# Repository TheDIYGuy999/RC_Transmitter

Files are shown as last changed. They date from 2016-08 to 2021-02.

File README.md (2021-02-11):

# This is an Arduino 2.4GHz radio and IR transmitter for Atmel AVR
## Features:
- IR transmitter for "LEGO" Powerfunctions and trains as well as for "MECCANO" motors
- 2.4GHz radio transmitter for RC cars, helicopters etc.
- 4 analog axes, 2 mode switches (joystick buttons)
- 1 potentiometer for adjustments like the MRSC stability control
- 4 push buttons for transmission mode and vehicle selection as well as menu navigation
- 20 seletcable vehicle addresses, so you can use it for more than one vehicle
- 3.3V, 8MHz Pro Mini (a Pro Micro is not supported anymore due to additional functionality)
- STM32 ARM version (deprecated) see: https://github.com/TheDIYGuy999/RC_Transmitter_STM32
- 2.4GHz NRF24L01 radio module
- Support for 0.96" I2C OLED
- Configuration menu for: Channel direction reversing, servo travel adjustment (independent for each vehicle)
- Configuration values are stored in EEPROM
- NRF24L01+PA+LNA SMA radio modules with power amplifier are supported from board version 1.1
- very compact
- Eagle PCB included
- PONG Game included

## Changelog:

New in V 1.3:
- Infrared codes for "MECCANO" IR controlled motors. Separate library required: https://github.com/TheDIYGuy999/MeccanoIr
- Multichannel transmission

New in V 1.4:
- 10 vehicle addresses instead of 5
- The "BACK" button can now be used (if the menu screen is not displayed on the OLED) as a momentary button, for example for a horn on the vehicle. It is sent as "data.momentary1"
- The "A6" potentiometer connector is now integrated in the code and is sent to the vehicle as "data.pot1"
- SimpleTimer library replaced with my own code, which uses significantly less memory
- EEPROM reset function added: press "Select" and "Back" during power on

New in V 1.41:
- Transmitter battery voltage now monitored correctly on 16MHz / 5V systems

New in V 1.42:
- Vehicle battery state change OLED bug fixed

New in V 1.43:
- Radio module sleep mode active while IR mode is in use

New in V 1.5:
- MECCANO IR support enhanced. Requires MECCANO library update to V 1.1

New in V 1.6:
- Buttons locked, if not required in selected transmission mode. This ensures, that no variables can be changed "in background"
- Automatic joystick zero point calibration after transmitter was switched on. This ensures, that you always have precise zero points, even if your potentiometers are not exacltly linear.

New in V 1.7:
- Support for 2 channel car style transmitters with steering wheel
- The transmitter type can be seletced in the new "transmitterConfig.h" file
- The potentiometers in some transmitters hit the mechanical endstop before the end of the electrical range is reached. This can now be compensated with the "range" variable

New in V 1.8:
- In most car style transmitters, the reverse range of the throttle potentiometer is smaller than the forward range.
- The reverse range is now multiplied by 4, to solve this problem

New in V 1.9:
- The "RC_Tester" functionality (https://github.com/TheDIYGuy999/RC_Tester) is now intergrated
- Useful, if you have more than one transmitter. Allows to visualize all 5 analog channels of your transmitter. The radio connection can be easily tested this way.
- Press "Select" during power on. The splash screen shows "Micro RC Tester" instead of "Micro RC Transmitter" and then a graphical screen, which visualizes all analog channels
- Works fo all 10 vehicle addresses

New in V 2.0:
- You have crashed your RC car? Then just play a little PONG session on your transmitter!
- Press "Back" during power on. The transittter is then activating the game mode :-)
- Press the "Back" button again to restart the game after "Game Over" is displayed

New in V 2.01:
- A serious bug in the mapJoystick() function was found during tests with the upcomming STM32 version
- The inverse and scale functionality did not work anymore since V2.0
- The bug is now solved and you can use the adjustments menu again

New in V 2.1:
- 3CH configuration for "car style" transmitter with additional 3 position switch added
- Used for 3 speed gearbox operation, using a single pole, double throw switch, connected to pin A0. Two resistors from A0 to GND and VCC allow 3 servo positions

New in V 2.2:
- 3CH configuration for WLtoys A959 etc. based 3+1CH transmitter (CONFIG_WLTOYS) See pictures below.
- Support for 3 position double throw switches (for gearbox switching etc.) added. Use two identical resistors (ca. 20k) from GND to center pin to VCC across the switch. Define a "CH1Switch" etc. variable., if a switch instead a potentiometer is connected
- New potentiometer calibration variable "reverseEndpoint" allows to adjust the throttle reverse range. Use the "Micro RC Tester" mode on a 2nd transmitter and then adjust the "range" variable as well, until the entire range of all channels is used on the graphical display.
- New "ledInversed" variable allows to use the stock WLtoys LED, which has a red and a green LED in one housing. The common pin is connected to VCC

New in V 2.3:
- 2+2CH configurarion for WLtoys transmitter added (CONFIG_WLTOYS)
- Allows to connect 3 buttons on CH4
- More than 3 buttons would be possible as well, but I ran out of space for more buttons
- Wiring see picture

New in V 2.4:
- Joystick ranges separatly adjustable for each channel in "transmitterConfig.h". This is required for the conversation of some car style transmitters, because they don't use the entire potentiometer range from end stop to end stop.

New in V 2.5:
- 20 vehicle addresses instead of 10
- Less RAM usage

New in V 2.51:
- Libraries comments added

## Usage

See pictures
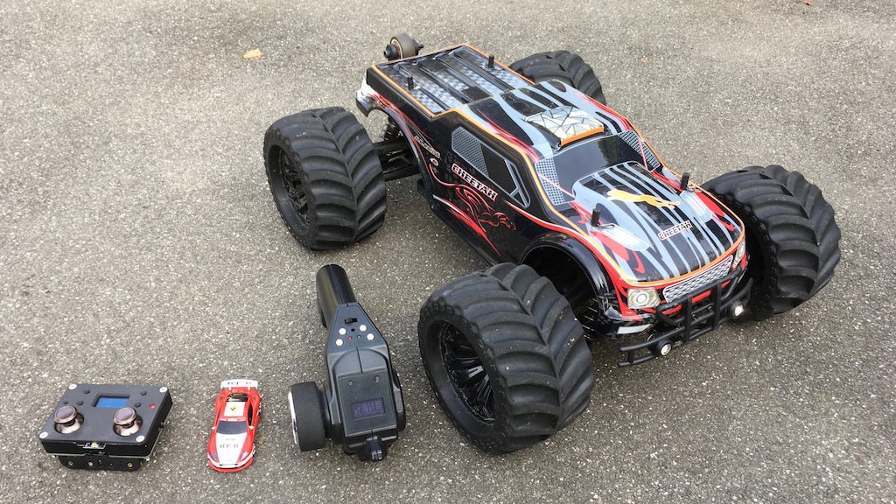
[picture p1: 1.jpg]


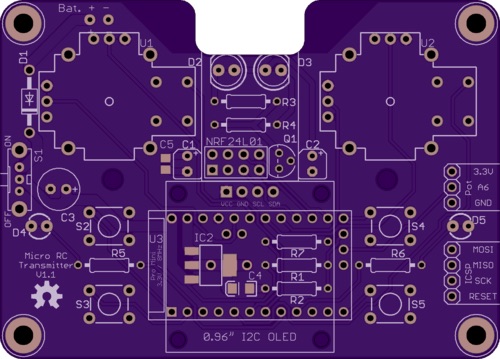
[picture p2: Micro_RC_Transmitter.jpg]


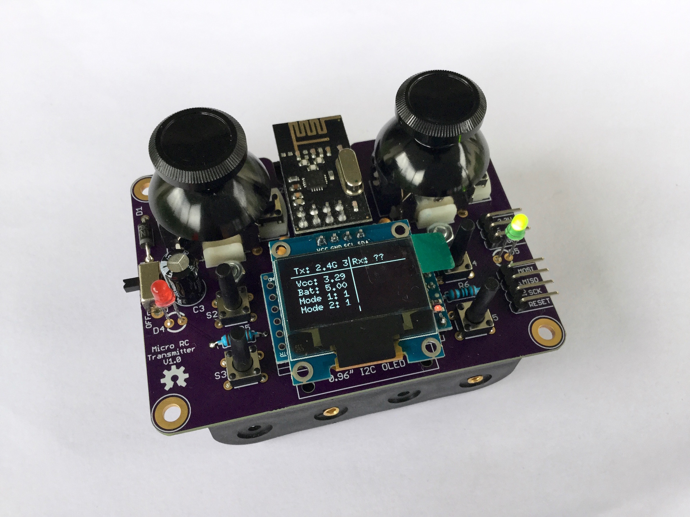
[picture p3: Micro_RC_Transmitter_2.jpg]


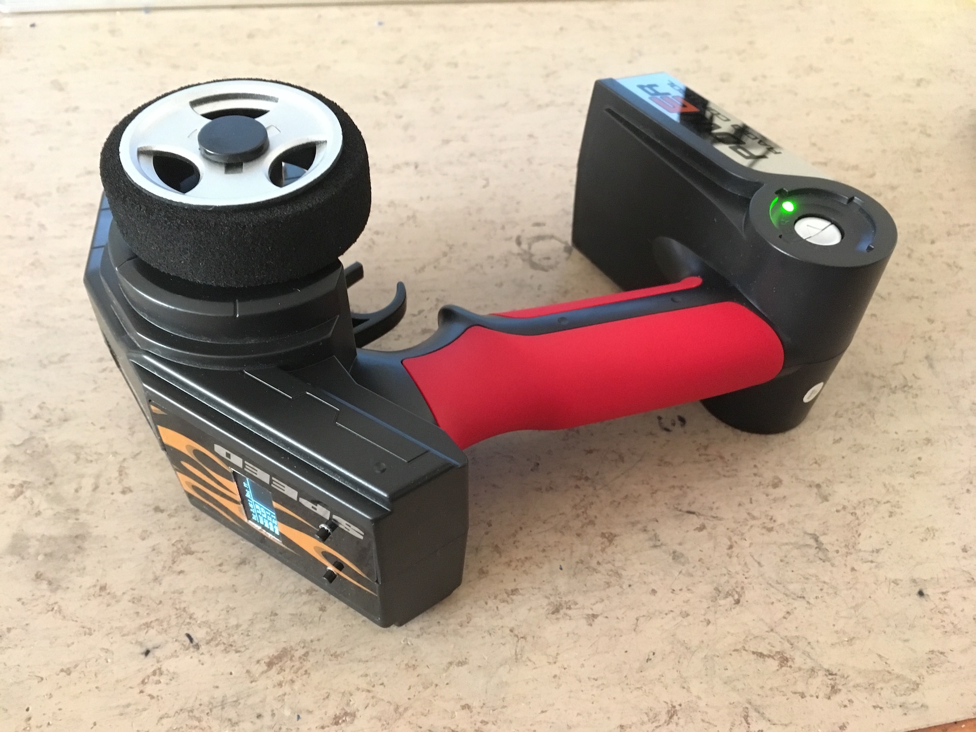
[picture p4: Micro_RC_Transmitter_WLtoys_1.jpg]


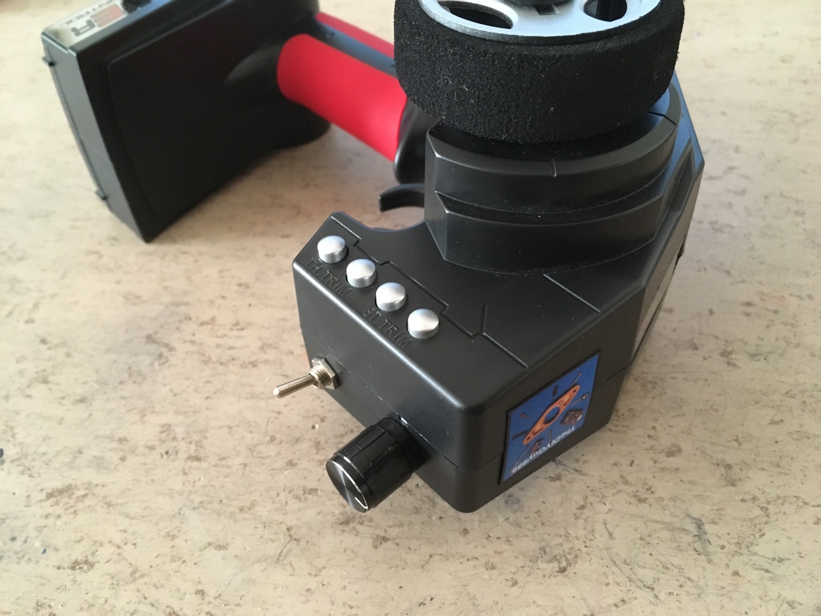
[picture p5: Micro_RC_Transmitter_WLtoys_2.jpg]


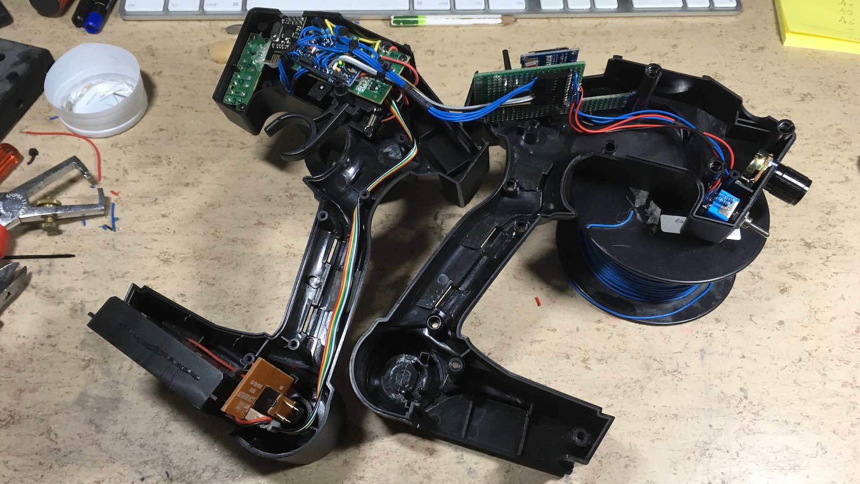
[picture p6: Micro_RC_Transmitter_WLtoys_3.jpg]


3 buttons wired to CH4
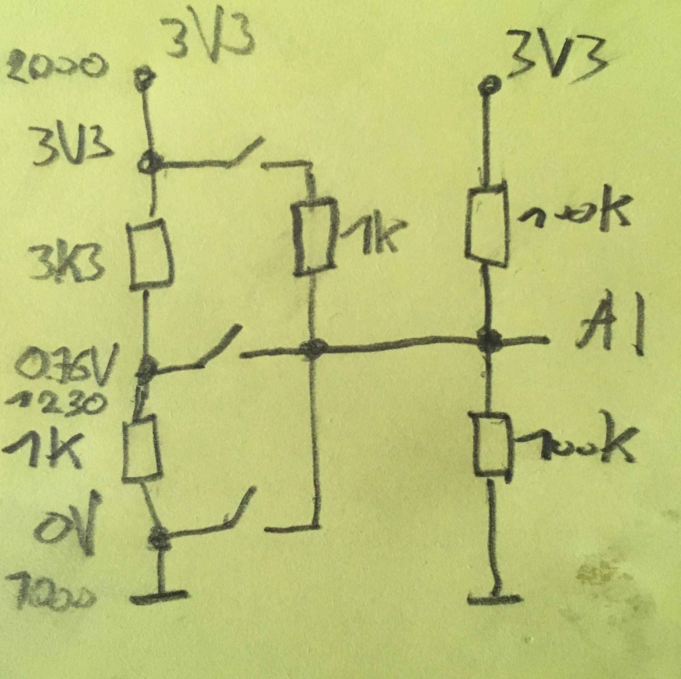
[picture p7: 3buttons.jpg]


3 position rocker switch wired to CH2 (for 3 speed transmission)
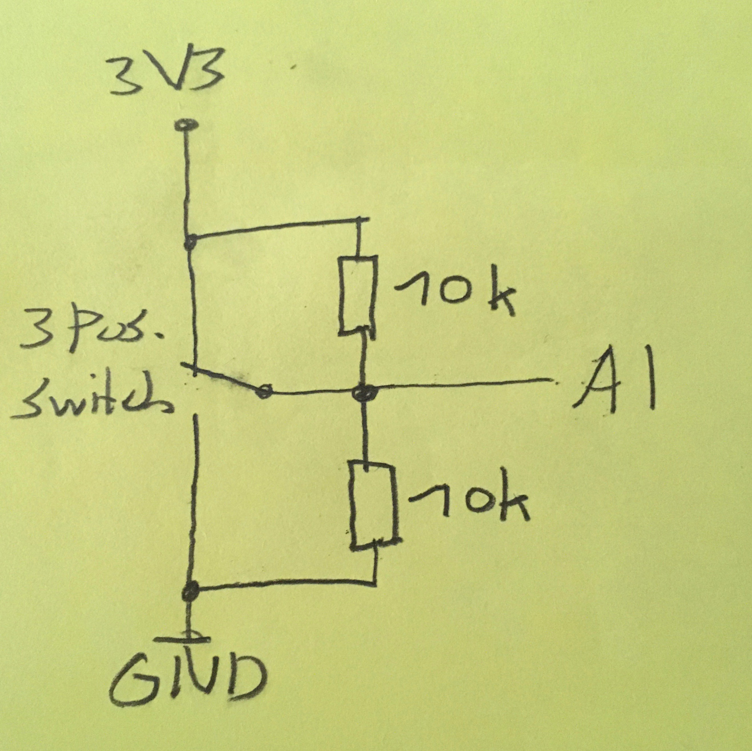
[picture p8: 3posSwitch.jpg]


(c) 2016-2020 TheDIYGuy999

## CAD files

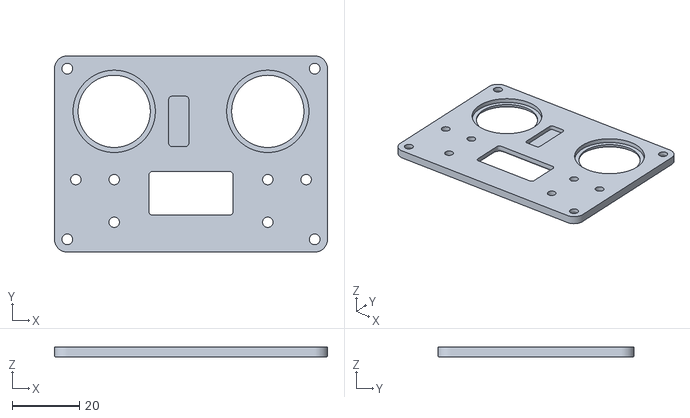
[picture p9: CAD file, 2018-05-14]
Housing/Transmitter Cover.stl
81.3 x 58.4 x 3.00

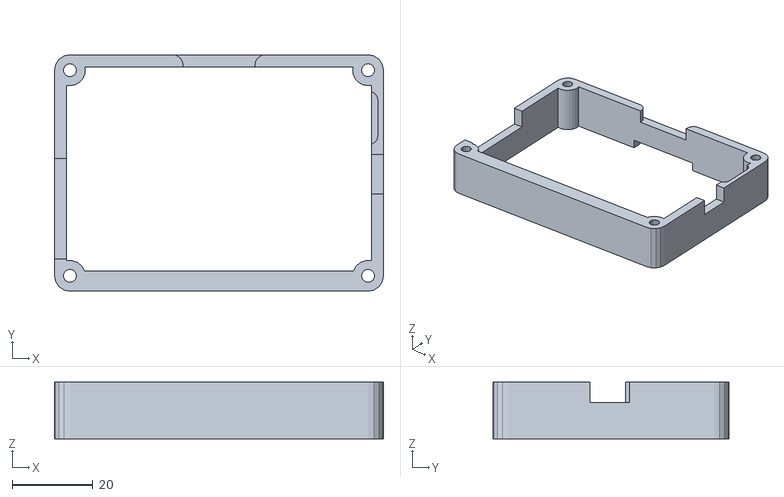
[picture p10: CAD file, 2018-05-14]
Housing/Transmitter Frame.stl
81.3 x 58.4 x 14.0

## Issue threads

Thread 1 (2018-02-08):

BOM missing

ybunyak, 2018-02-08:
Hi,

Is it possible to provide BOM for the transmitter, like you did for Micro_RC_Receiver?

Thanks.

johnlenfr, 2020-04-11:
In the Eagle File you can find the BOM

glisandro, 2023-05-11:
joysticks are those of XBOX?

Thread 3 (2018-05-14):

Housing

ybunyak, 2018-05-14:
Could you please share .stl files for the housing like you did for the receiver?

TheDIYGuy999, 2018-05-14:
Sorry for the delay. They are now available.

ybunyak, 2018-05-14:
Thank you. Will post images of my project when it's done ;)

Closed 2018-05-14.

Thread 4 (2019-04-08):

Question: RC Transmitter

JpEncausse, 2019-04-08:
Hi,
Sorry if my question is stupid,

I'd like to setup an "Arduino Bridge" between an RC Car WLtoys K989 and a computer.
Sending WebSocket/HTTP command to the Arduino then to the RC Car Receiver.
(Yes I know, lag will be a problem)

Should I start with RC_Transmitter repository code ? Or is there a lighweight version / article ?
Thanks

jindaxia, 2019-05-19:
ESP8266 ?

TheDIYGuy999, 2019-05-19:
There is no ESP8266 version, but one for STM32: https://github.com/TheDIYGuy999/RC_Transmitter_STM32

Ahmedabdulamir, 2019-05-28:
Hi, I want to start building similar transmitter. Do I need Pro Mini 168 or 328 for the transmitter?. Also what about the receiver?

I like your work BTW, its so proffessional

Thanks

TheDIYGuy999, 2019-05-28:
Hi,  you need the 328 version. Both the transmitter and the receiver use the same Atmel IC.

Also have a look at the manual in the transmitter section.

Thanks for the praise

Ahmedabdulamir, 2019-05-28:
Thanks for you kind reply. Can I use 5v Pro mini instead of 3.3v version?

jindaxia, 2019-05-29:
#5   YES！

TheDIYGuy999, 2019-05-29:
Yes, but you have to make sure, that your battery voltage is at least 5.5V (before the 5V regulator) and that your radio module is supplied with 3.3V, using a separate regulator.

jindaxia, 2019-05-30:
now I use 16M/3.3v， it‘s ok
I replaced the MIC5205 with a 3.3v version on the board， the MIC5205-3.3 is very easy to get，

Ahmedabdulamir, 2019-05-30:
Thanks I got it. I think its best to use the 3.3v instead of using another regulator for the RF module. Thanks to all for your comments

sosssego, 2021-01-28:
Can I use this to make 3 rc car/radios to work together?

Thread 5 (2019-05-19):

What will happening if I use the 5V/16Mhz pro mini

jindaxia, 2019-05-19:
I only have 5v/16mhz pro mini ， how if i can use this board？

TheDIYGuy999, 2019-05-19:
You can use it, but make sure the NRF24 radio module is supplied by 3.3V. Also make sure, that your minimum battery voltage is about 5.7V

jindaxia, 2019-05-20:
Thanks，

jindaxia, 2019-05-21:
finally，  I replaced the MIC2505 with the 3.3v version on the board

Closed 2019-05-20.

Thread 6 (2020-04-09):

Connection/pairing problem

Kiriki-kun, 2020-04-09:
Hi,

I assembled transmitter and receiver.
Transmitter is working, i can operate menu.
I can't verify if receiver is working, because there is no indication of work.
Receiver should be set to ID 1.
I checked the radio voltage and all connections. They are good.

When i power up the receiver and transmitter, they won't connect.
Is there another step to pair them?
Do you have any suggestion what to check?
After few hours I'm out of ideas.

Thanks for help
Kiriki

TheDIYGuy999, 2020-04-09:
Hi, really hard to tell. The code is uploading without issues? If you have a 2nd transmitter, you can also use it as a receiver with graphical feedback, according to the manual.

Are you sure your receiver is programmed with ID 1? Maybe, one of your NRF24 radio modules is defective?

Kiriki-kun, 2020-04-09:
Thank you for your answer.
I have problem with verificatio after writing, but writing is working good. I flashed different configuration to transmitter, and i could see the difference after turning it on.
I dont have second transmitter, i will order parts if everything else fail (i used all my spare sparts just to make one run :)).
I will try to write simple code just to test if radio modules are working.

So i assume, that transmitter and receiver should pair after couple of seconds, without additional steps? Just turn both on, and wait?

Kiriki-kun, 2020-04-10:
Can it be because i have 16 Mhz arduino in transmitter, and 8 Mhz in receiver?

TheDIYGuy999, 2020-04-10:
No, it does not matter (if your boot loader is the right one for the frequency), but what is your transmitter battery voltage? Is it high enough for stable 5V VCC? And yes, they should pair immediately, if they are on the same channel. You could try to add a 100nF ceramic capacitor across the NFRF module 3.3V & GND pins, it makes the receiver radio much more stable, at least in my case. All the solder joints are looking god with a magnifier? Maybe you can post pictures?

johnlenfr, 2020-04-11:
@Kiriki-kun : seams like you have a problem with initialization of NRF24.

Test your NRF24 with simple code before testing the transmiter code of @TheDIYGuy999

See https://forum.arduino.cc/index.php?topic=421081.0

Kiriki-kun, 2020-04-17:
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
Hi,
Right now, i managed to setup serial monitor and run debug code. I'm attaching printed debug.
I can see that all anthena parameters are empty, but i'm not sure if they are not filled after establishing the connection.
Can you look at it? This is how debug should look like for not connected transmitter or receiver?

Kiriki-kun, 2020-04-22:
ok, i made it work.
Not really sure what wasn't working. I tried few test programs, resoldered radios, and now it's working :)
Thank you very much for yor help :)

TheDIYGuy999, 2020-04-22:
Great. I knew you would solve the issue. Well done and have fun with it. I would love to see pictures of your work, if possible. And sorry, I forgot to answer your previous question.

Closed 2020-04-22.

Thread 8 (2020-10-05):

Expected variable ranges

debonthj, 2020-10-05:
Great project! I am building this into a RC car style pistol grip transmitter, different brand though than the WLToys. What are the expected ranges of the wheel left/right and throttle fwd/rev that are being sent to the receiver? What I am getting right now:

Throttle: fwd = 72, mid = 50, rev = 37
Steer: left = 37, mid = 50, right =63.

Is this correct or should it be a range between 0-100?

I may not be understanding this correctly:

`// Joystick calibration
int range = 1023; // 1023, if entire pot wiper range is used
int reverseEndpoint = 0; // the point, where the throttle joystick hits its reverse end stop
`

debonthj, 2020-10-05:
These are the raw values from the signal wires of the throttle and steering wheel pots via AnalogRead on A1 (steering) and A3 (throttle), pots powered by 5V and GND.

A1 (steering)

- 320 (left)
- 447 (neutral)
- 585 (right)

A3 (throttle)

- 682 (go)
- 460 (neutral)
- 332 (rev)

debonthj, 2020-10-05:
Thanks. Through trial and error I got a good range setting (640). This gives me the full range for steering, as well as the throttle reverse, but for throttle FWD it gets to 100 at around 2/3 of the trigger position. reverseEndpoint does not seem to have an impact. I suppose a separate range is needed for steering and throttle given the differences in their resistances as per above. Not a huge issue but something I may code in in the future if this project gets alot of use. FYI the transmitter is this: https://www.carson-modelsport.com/en/products/carson-modelsport/accessories/radio-controls/reflex-wheel-start-24g-radio-white-500500103/

Thanks again!

TheDIYGuy999, 2020-10-05:
Thanks for the feedback. Yes, a separate range might be useful, but for my transmitters it was not required so far.

Closed 2020-10-05.

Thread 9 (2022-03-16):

| Question | Is there a wiring diagram or documentation for the "2+1 channel car type" transmitter?

zinixyt, 2022-03-16:
Hi, is there any documentation or diagrams for the transmitter type above that im missing?
If yes then i need help.

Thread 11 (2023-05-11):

Problem with screen pins

glisandro, 2023-05-11:
Hi,
The OLED screen I have has the GND and VCC pins swapped with respect to the pcb

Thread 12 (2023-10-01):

Can not seem to get it to verify

hendr13x, 2023-10-01:
HI I'm using Arduino IDE 2.2.1

opening a fresh copy of the RC Transmitter code and I believe all the required Library's including your version on statusLED
i can not seem to get the code to verify
 it gets to greenLED.begin(6); // Green LED on pin 5
and gets the following error
Compilation error: no matching function for call to 'statusLED::begin(int)'

im at a loss as to what i have done wrong with it.

any help would be appreciated or if you are able to send or upload a complete with all included files.

Thank you

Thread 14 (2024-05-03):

Compilation error for the Arduino Pro or Pro Mini board

01makar, 2024-05-03:
hello. I'm trying to flash the transmitter, but when compiling the sketch it gives an error: "Compilation error for the Arduino Pro or Pro Mini board." please tell me how to fix it.

01makar, 2024-05-06:
I recorded the bootloader, when recording the transmitter sketch through the programmer after compilation, it displays the following message: Compilation error for TheDIYGuy999 328P board (8 MHz ext. Oscillator)

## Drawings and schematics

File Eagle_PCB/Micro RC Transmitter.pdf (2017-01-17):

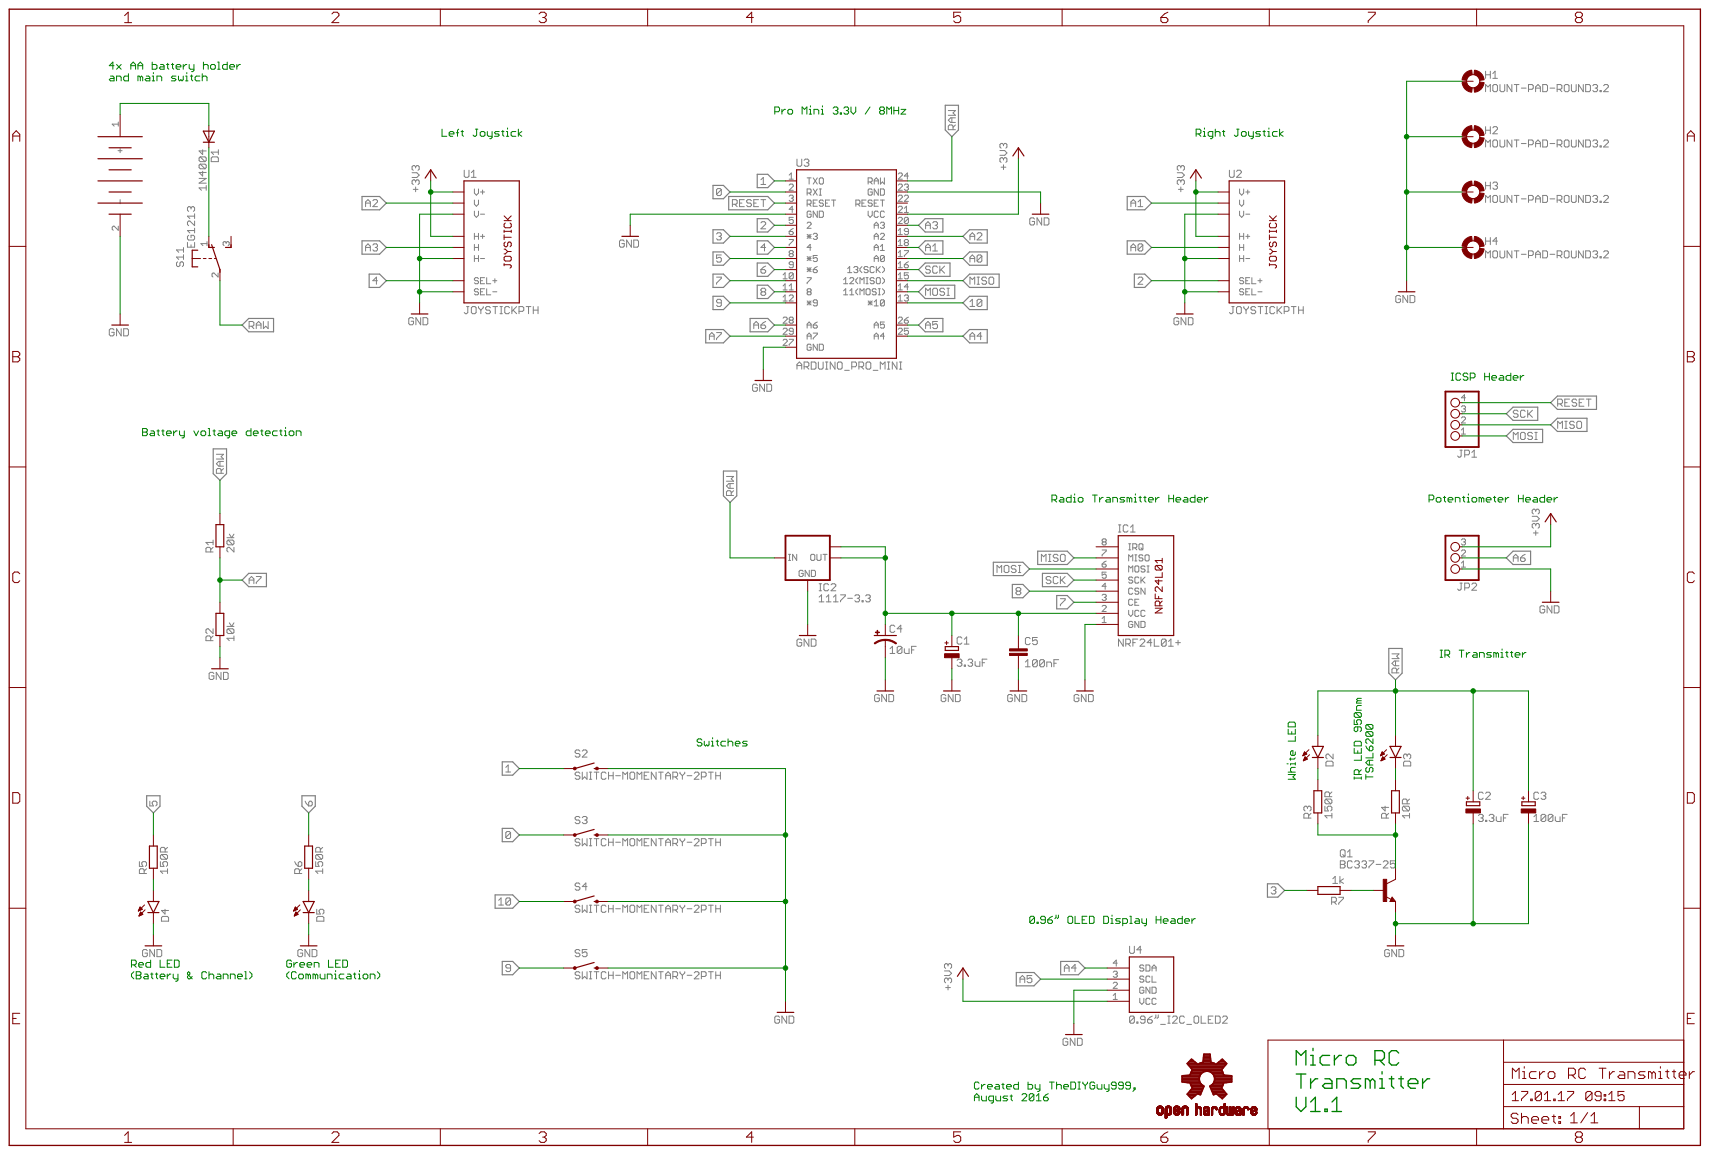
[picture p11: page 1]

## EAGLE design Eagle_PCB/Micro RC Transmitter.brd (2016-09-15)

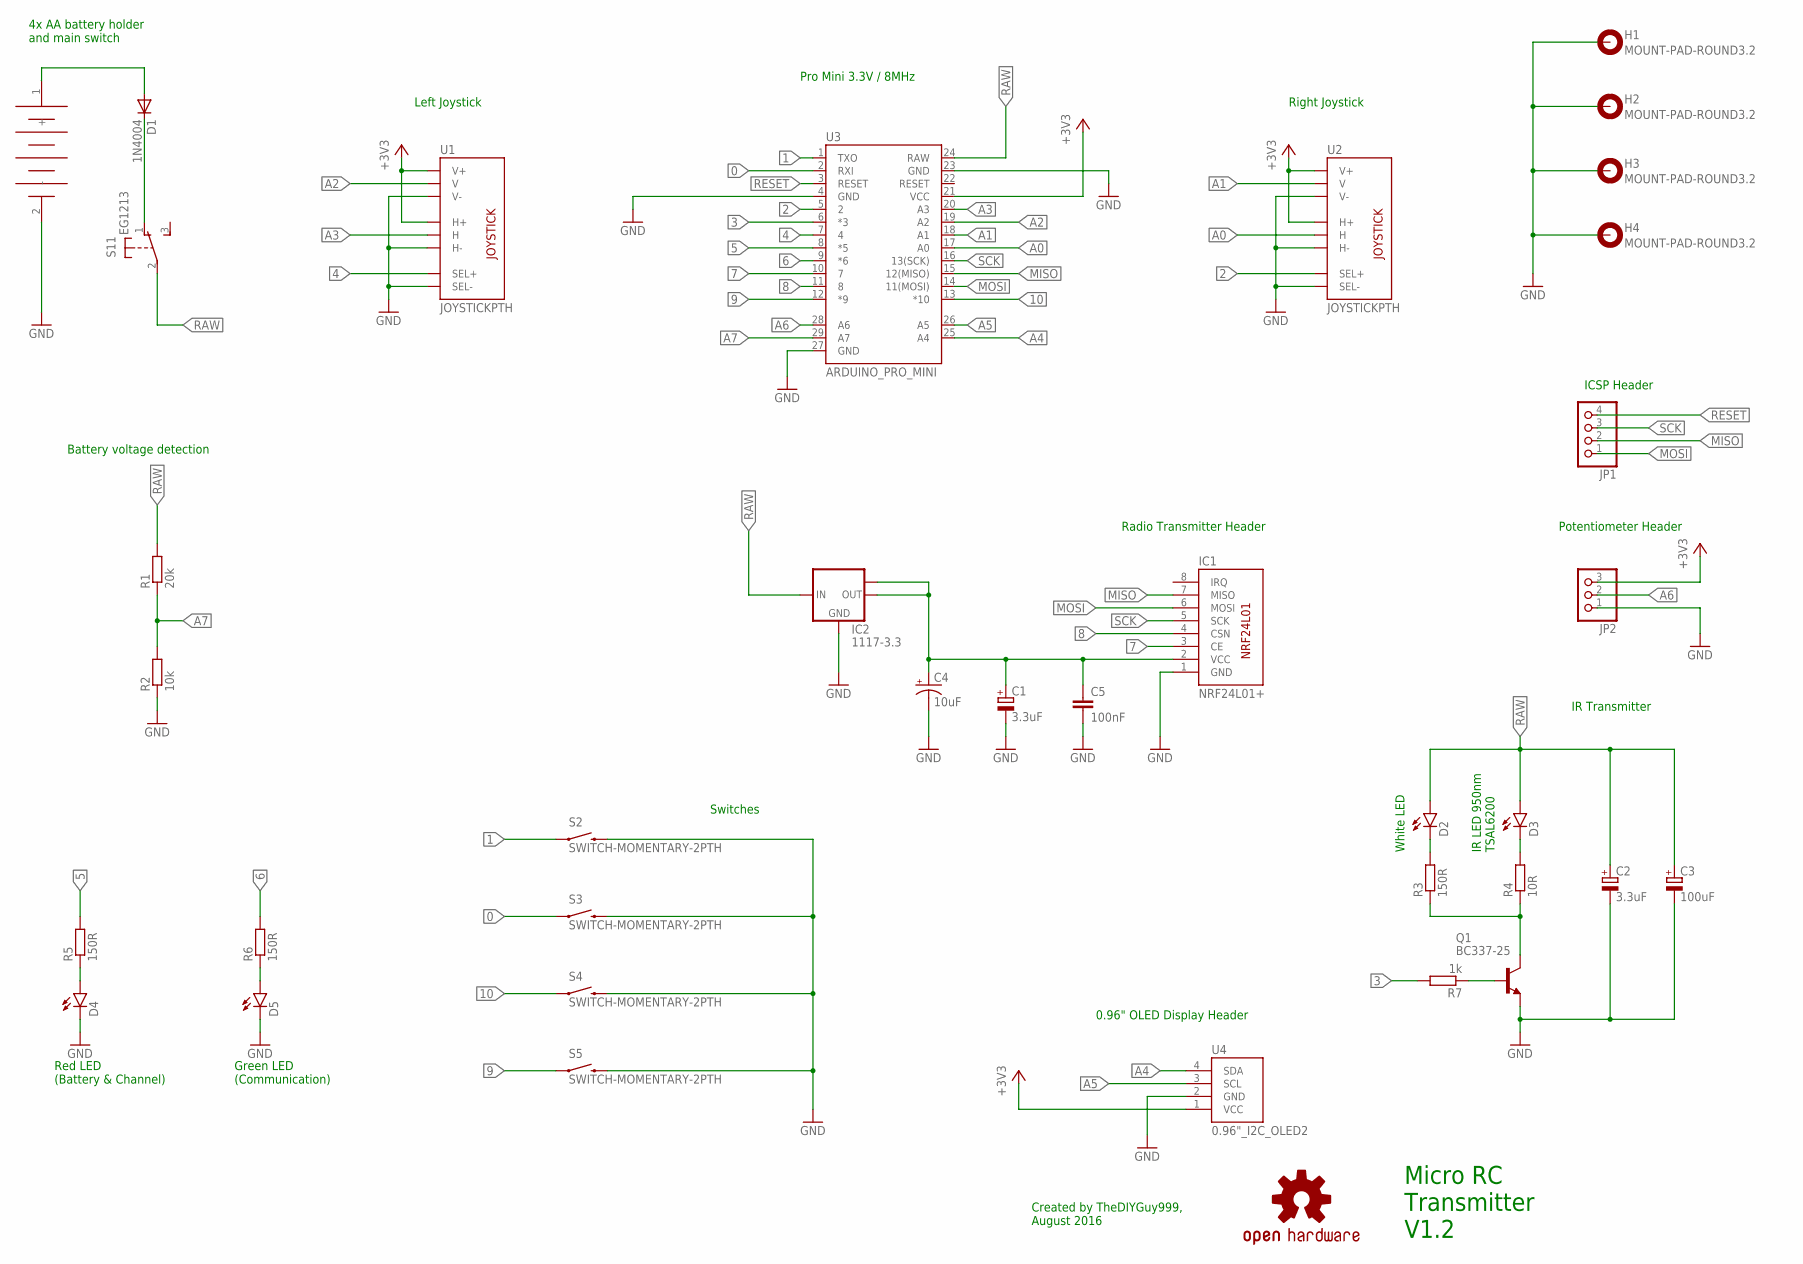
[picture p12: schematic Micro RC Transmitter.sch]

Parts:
C1, C2: 3.3uF; B45181A
C3: 100uF; E2,5-7
C4: 10uF; EIA3216
C5: 100nF; C0805
D1: 1N4004; DO41-10
D2, D3: LED5MM
D4, D5: LED3MM
G1: 4X_AA_BATTERY_HOLDER
H1, H2, H3, H4: MOUNT-PAD-ROUND3.2; 3,2-PAD
IC1: NRF24L01+; NRF24L01
IC2: 1117-3.3; SOT223
JP1: PINHD-1X4; 1X04
JP2: PINHD-1X3; 1X03
LOGO1: OSHW-LOGOM; OSHW-LOGO-M
Q1: BC337-25; TO92
R1: 20k; 0207/10
R2: 10k; 0207/10
R3, R5, R6: 150R; 0207/10
R4: 10R; 0207/10
R7: 1k; 0207/10
S1: EG1213
S2, S3, S4, S5: SWITCH-MOMENTARY-2PTH; TACTILE-PTH
U1, U2: JOYSTICKPTH; JOYSTICK
U3: ARDUINO_PRO_MINI
U4: 0.96"_I2C_OLED2; 0.96"_I2C_OLED_2

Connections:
0: S3.1, U3.2 (RXI)
1: S2.1, U3.1 (TXO)
2: U2.B1A (SEL+), U3.5 (2)
3: R7.2, U3.6 (*3)
4: U1.B1A (SEL+), U3.7 (4)
5: R5.2, U3.8 (*5)
6: R6.2, U3.9 (*6)
7: IC1.3 (CE), U3.10 (7)
8: IC1.4 (CSN), U3.11 (8)
9: S5.1, U3.12 (*9)
10: S4.1, U3.13 (*10)
+3V3: JP2.3, U1.H1 (H+), U1.V1 (V+), U2.H1 (H+), U2.V1 (V+), U3.21 (VCC), U4.1 (VCC)
A0: U2.H2 (H), U3.17 (A0)
A1: U2.V2 (V), U3.18 (A1)
A2: U1.V2 (V), U3.19 (A2)
A3: U1.H2 (H), U3.20 (A3)
A4: U3.25 (A4), U4.4 (SDA)
A5: U3.26 (A5), U4.3 (SCL)
A6: JP2.2, U3.28 (A6)
A7: R1.1, R2.2, U3.29 (A7)
GND: C1.-, C2.-, C3.-, C4.C (-), C5.2, D4.K (C), D5.K (C), G1.2 (-), H1.B3,2, H2.B3,2, H3.B3,2, H4.B3,2, IC1.1 (GND), IC2.1 (GND), JP2.1, Q1.1 (E), R2.1, S2.3 (2), S3.3 (2), S4.3 (2), S5.3 (2), U1.B2A (SEL-), U1.H3 (H-), U1.V3 (V-), U2.B2A (SEL-), U2.H3 (H-), U2.V3 (V-), U3.4 (GND), U3.23 (GND), U3.27 (GND), U4.2 (GND)
MISO: IC1.7 (MISO), JP1.2, U3.15 (12(MISO))
MOSI: IC1.6 (MOSI), JP1.1, U3.14 (11(MOSI))
unnamed: D4.A, R5.1
unnamed: D5.A, R6.1
unnamed: Q1.3 (C), R3.1, R4.1
unnamed: D3.K (C), R4.2
unnamed: Q1.2 (B), R7.1
unnamed: D2.K (C), R3.2
unnamed: D1.A, G1.1 (+)
unnamed: D1.C, S1.1 (O)
unnamed: C1.+, C4.A (+), C5.1, IC1.2 (VCC), IC2.2 (OUT), IC2.TAB (OUT1)
RAW: C2.+, C3.+, D2.A, D3.A, IC2.3 (IN), R1.2, S1.2, U3.24 (RAW)
RESET: JP1.4, U3.3 (RESET)
SCK: IC1.5 (SCK), JP1.3, U3.16 (13(SCK))

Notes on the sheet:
Red LED (Battery & Channel)
Green LED (Communication)
Micro RC Transmitter V1.2
White LED
IR LED 950nm TSAL6200
IR Transmitter
Radio Transmitter Header
4x AA battery holder and main switch
Left Joystick
Right Joystick
0.96" OLED Display Header
Battery voltage detection
Switches
ICSP Header
Pro Mini 3.3V / 8MHz
Potentiometer Header
Created by TheDIYGuy999, August 2016

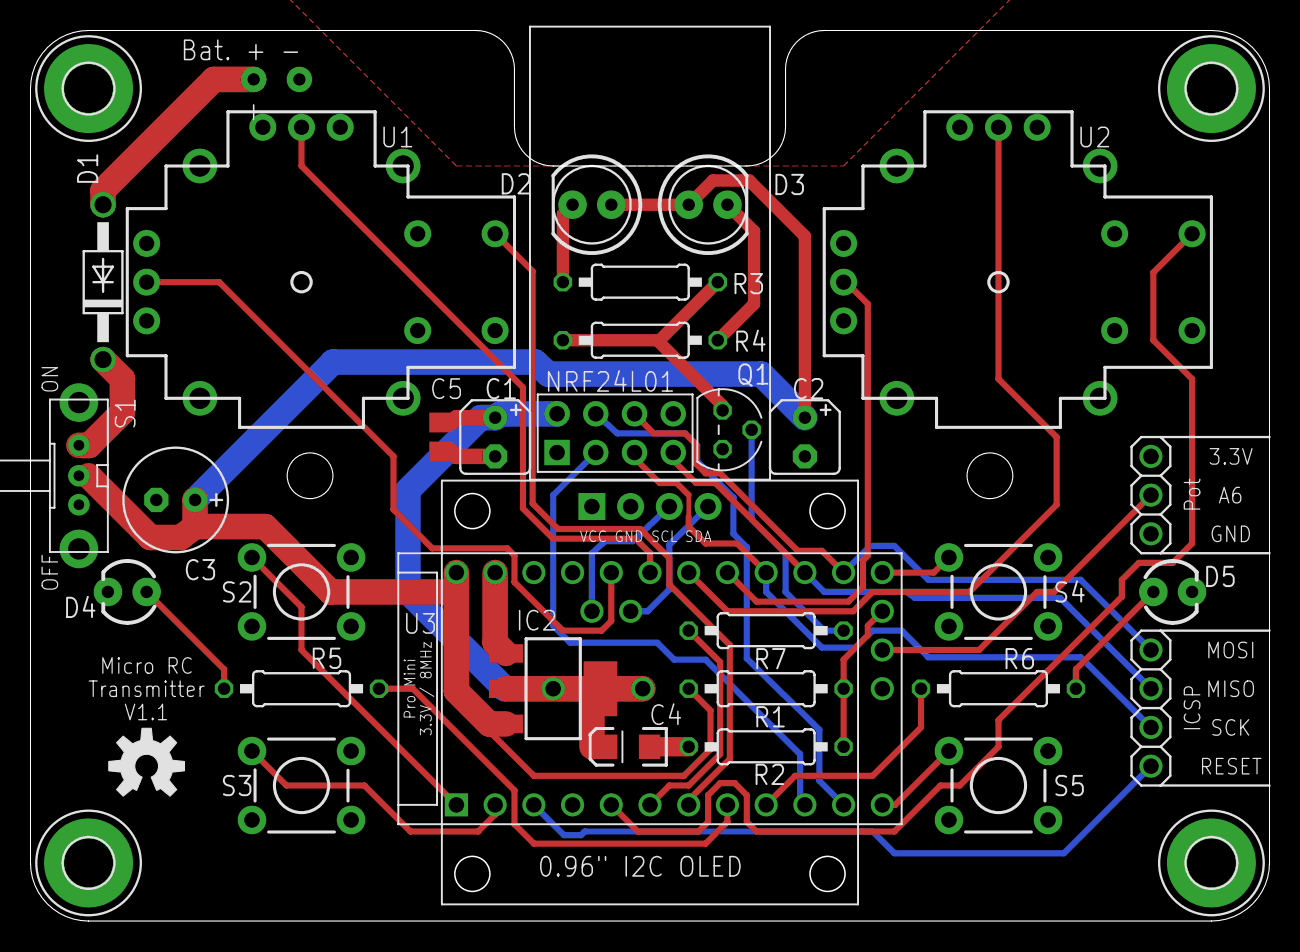
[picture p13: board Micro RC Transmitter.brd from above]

Board: 2 copper layers, 81.3 x 58.4 mm, 37 parts (1 on the bottom side), 35 nets.

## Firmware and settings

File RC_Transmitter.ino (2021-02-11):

// Micro RC Project. A tiny little 2.4GHz and LEGO "Power Functions" / "MECCANO" IR RC transmitter!
// 3.3V, 8MHz Pro Mini
// STM32F103C8T6 ARM version see: https://github.com/TheDIYGuy999/RC_Transmitter_STM32
// 2.4GHz NRF24L01 radio module
// SSD 1306 128 x 63 0.96" OLED
// Custom PCB from OSH Park
// Menu for the following adjustments:
// -Channel reversing
// -Channel travel limitation adjustable in steps of 5%
// -Value changes are stored in EEPROM, individually per vehicle
// Radio transmitter tester included (press "Select" button during power up)
// NRF24L01+PA+LNA SMA radio modules with power amplifier are supported from board version 1.1
// ATARI PONG game :-) Press the "Back" button during power on to start it

const float codeVersion = 2.51; // Software revision

//
// =======================================================================================================
// BUILD OPTIONS (comment out unneeded options)
// =======================================================================================================
//

//#define DEBUG // if not commented out, Serial.print() is active! For debugging only!!
//#define OLED_DEBUG // if not commented out, an additional diagnostics screen is shown during startup

//
// =======================================================================================================
// INCLUDE LIRBARIES & TABS
// =======================================================================================================
//

// Libraries
#include <SPI.h>
#include <RF24.h> // Installed via Sketch > Include Library > Manage Libraries > Type "RF24" (use V1.3.3!)
#include <printf.h>
#include <EEPROMex.h> // https://github.com/thijse/Arduino-EEPROMEx
#include <LegoIr.h> // https://github.com/TheDIYGuy999/LegoIr
#include <statusLED.h> // https://github.com/TheDIYGuy999/statusLED
#include <U8glib.h> // Installed via Sketch > Include Library > Manage Libraries > Type "U8glib"

// Tabs
#include "transmitterConfig.h"
// More tabs (.h files in the sketch directory) see further down

//
// =======================================================================================================
// PIN ASSIGNMENTS & GLOBAL VARIABLES
// =======================================================================================================
//

// Is the radio or IR transmission mode active?
byte transmissionMode = 1; // Radio mode is active by default

// Select trannsmitter operation mode
byte operationMode = 0; // Start in transmitter mode (0 = transmitter mode, 1 = tester mode, 2 = game mode)

// Vehicle address
int vehicleNumber = 1; // Vehicle number one is active by default

// Radio channels (126 channels are supported)
byte chPointer = 0; // Channel 1 (the first entry of the array) is active by default
const byte NRFchannel[] {
  1, 2
};

// the ID number of the used "radio pipe" must match with the selected ID on the transmitter!
// 20 ID's are available @ the moment
const uint64_t pipeOut[] PROGMEM = {
  0xE9E8F0F0B1LL, 0xE9E8F0F0B2LL, 0xE9E8F0F0B3LL, 0xE9E8F0F0B4LL, 0xE9E8F0F0B5LL,
  0xE9E8F0F0B6LL, 0xE9E8F0F0B7LL, 0xE9E8F0F0B8LL, 0xE9E8F0F0B9LL, 0xE9E8F0F0B0LL,
  0xE9E8F0F0C1LL, 0xE9E8F0F0C2LL, 0xE9E8F0F0C3LL, 0xE9E8F0F0C4LL, 0xE9E8F0F0C5LL,
  0xE9E8F0F0C6LL, 0xE9E8F0F0C7LL, 0xE9E8F0F0C8LL, 0xE9E8F0F0C9LL, 0xE9E8F0F0C0LL
};
const int maxVehicleNumber = (sizeof(pipeOut) / (sizeof(uint64_t)));

// Hardware configuration: Set up nRF24L01 radio on hardware SPI bus & pins 7 (CE) & 8 (CSN)
RF24 radio(7, 8);

// The size of this struct should not exceed 32 bytes
struct RcData {
  byte axis1; // Aileron (Steering for car)
  byte axis2; // Elevator
  byte axis3; // Throttle
  byte axis4; // Rudder
  boolean mode1 = false; // Mode1 (toggle speed limitation)
  boolean mode2 = false; // Mode2 (toggle acc. / dec. limitation)
  boolean momentary1 = false; // Momentary push button
  byte pot1; // Potentiometer
};
RcData data;

// This struct defines data, which are embedded inside the ACK payload
struct ackPayload {
  float vcc; // vehicle vcc voltage
  float batteryVoltage; // vehicle battery voltage
  boolean batteryOk; // the vehicle battery voltage is OK!
  byte channel = 1; // the channel number
};
ackPayload payload;

// Did the receiver acknowledge the sent data?
boolean transmissionState;

// LEGO powerfunctions IR
LegoIr pf;
int pfChannel;
const int pfMaxAddress = 3;

// TX voltages
boolean batteryOkTx = false;
#define BATTERY_DETECT_PIN A7 // The 20k & 10k battery detection voltage divider is connected to pin A7
float txVcc;
float txBatt;

//Joystick reversing
boolean joystickReversed[maxVehicleNumber + 1][4] = { // 1 + 10 Vehicle Addresses, 4 Servos
  {false, false, false, false}, // Address 0 used for EEPROM initialisation

  {false, false, false, false}, // Address 1
  {false, false, false, false}, // Address 2
  {false, false, false, false}, // Address 3
  {false, false, false, false}, // Address 4
  {false, false, false, false}, // Address 5
  {false, false, false, false}, // Address 6
  {false, false, false, false}, // Address 7
  {false, false, false, false}, // Address 8
  {false, false, false, false}, // Address 9
  {false, false, false, false}, // Address 10
};

//Joystick percent negative
byte joystickPercentNegative[maxVehicleNumber + 1][4] = { // 1 + 10 Vehicle Addresses, 4 Servos
  {100, 100, 100, 100}, // Address 0 not used

  {100, 100, 100, 100}, // Address 1
  {100, 100, 100, 100}, // Address 2
  {100, 100, 100, 100}, // Address 3
  {100, 100, 100, 100}, // Address 4
  {100, 100, 100, 100}, // Address 5
  {100, 100, 100, 100}, // Address 6
  {100, 100, 100, 100}, // Address 7
  {100, 100, 100, 100}, // Address 8
  {100, 100, 100, 100}, // Address 9
  {100, 100, 100, 100}, // Address 10
};

//Joystick percent positive
byte joystickPercentPositive[maxVehicleNumber + 1][4] = { // 1 + 10 Vehicle Addresses, 4 Channels
  {100, 100, 100, 100}, // Address 0 not used

  {100, 100, 100, 100}, // Address 1
  {100, 100, 100, 100}, // Address 2
  {100, 100, 100, 100}, // Address 3
  {100, 100, 100, 100}, // Address 4
  {100, 100, 100, 100}, // Address 5
  {100, 100, 100, 100}, // Address 6
  {100, 100, 100, 100}, // Address 7
  {100, 100, 100, 100}, // Address 8
  {100, 100, 100, 100}, // Address 9
  {100, 100, 100, 100}, // Address 10
};

// Joysticks
#define JOYSTICK_1 A1
#define JOYSTICK_2 A0
#define JOYSTICK_3 A3
#define JOYSTICK_4 A2

// Joystick push buttons
#define JOYSTICK_BUTTON_LEFT 4
#define JOYSTICK_BUTTON_RIGHT 2

byte leftJoystickButtonState;
byte rightJoystickButtonState;

// Buttons
#define BUTTON_LEFT 1 // - or channel select
#define BUTTON_RIGHT 10 // + or transmission mode select
#define BUTTON_SEL 0 // select button for menu
#define BUTTON_BACK 9 // back button for menu

byte leftButtonState = 7; // init states with 7 (see macro below)!
byte rightButtonState = 7;
byte selButtonState = 7;
byte backButtonState = 7;

// macro for detection of rising edge and debouncing
/*the state argument (which must be a variable) records the current and the last 3 reads
  by shifting one bit to the left at each read and bitwise anding with 15 (=0b1111).
  If the value is 7(=0b0111) we have one raising edge followed by 3 consecutive 1's.
  That would qualify as a debounced raising edge*/
#define DRE(signal, state) (state=(state<<1)|(signal&1)&15)==7

// Status LED objects (false = logic not inverted)
#ifdef ledInversed // inversed logic
statusLED greenLED(true); // green: ON = transmitter ON, flashing = Communication with vehicle OK
statusLED redLED(true); // red: ON = battery empty
#endif
#ifndef ledInversed // not inversed logic
statusLED greenLED(false); // green: ON = transmitter ON, flashing = Communication with vehicle OK
statusLED redLED(false); // red: ON = battery empty
#endif

// OLED display. Select the one you have! Otherwise sthe sreen could be slightly offset sideways!
//U8GLIB_SH1106_128X64 u8g(U8G_I2C_OPT_FAST);  // I2C / TWI  FAST instead of NONE = 400kHz I2C!
U8GLIB_SSD1306_128X64 u8g(U8G_I2C_OPT_FAST);  // I2C / TWI  FAST instead of NONE = 400kHz I2C!
int activeScreen = 0; // the currently displayed screen number (0 = splash screen)
boolean displayLocked = true;
byte menuRow = 0; // Menu active cursor line

// EEPROM (max. total size is 512 bytes)
// Always get the adresses first and in the same order
// Blocks of 21 x 4 bytes = 84 bytes each!
int addressReverse = EEPROM.getAddress(sizeof(byte) * 84);
int addressNegative = EEPROM.getAddress(sizeof(byte) * 84);
int addressPositive = EEPROM.getAddress(sizeof(byte) * 84);

//
// =======================================================================================================
// INCLUDE TABS (header files in sketch directory)
// =======================================================================================================
//

// Tabs (header files in sketch directory)
#include "readVCC.h"
//#include "transmitterConfig.h"
#include "MeccanoIr.h" // https://github.com/TheDIYGuy999/MeccanoIr
#include "pong.h" // A little pong game :-)
#include "pgmRead64.h" // Read 64 bit blocks from PROGMEM

//
// =======================================================================================================
// RADIO SETUP
// =======================================================================================================
//

void setupRadio() {
  radio.begin();
  radio.setChannel(NRFchannel[chPointer]);

  radio.powerUp();

  // Set Power Amplifier (PA) level to one of four levels: RF24_PA_MIN, RF24_PA_LOW, RF24_PA_HIGH and RF24_PA_MAX
  if (boardVersion < 1.1 ) radio.setPALevel(RF24_PA_MIN); // No independent NRF24L01 3.3V PSU, so only "MIN" transmission level allowed
  else radio.setPALevel(RF24_PA_MAX); // Independent NRF24L01 3.3V PSU, so "FULL" transmission level allowed

  radio.setDataRate(RF24_250KBPS);
  //radio.setAutoAck(pipeOut[vehicleNumber - 1], true); // Ensure autoACK is enabled
  radio.setAutoAck(pgm_read_64(&pipeOut, vehicleNumber - 1), true); // Ensure autoACK is enabled
  radio.enableAckPayload();
  radio.enableDynamicPayloads();
  radio.setRetries(5, 5);                  // 5x250us delay (blocking!!), max. 5 retries
  //radio.setCRCLength(RF24_CRC_8);          // Use 8-bit CRC for performance*/

#ifdef DEBUG
  radio.printDetails();
  delay(1800);
#endif

  // All axes to neutral position
  data.axis1 = 50;
  data.axis2 = 50;
  data.axis3 = 50;
  data.axis4 = 50;

  // Transmitter
  if (operationMode == 0) {
    //radio.openWritingPipe(pipeOut[vehicleNumber - 1]); // Vehicle Number 1 = Array number 0, so -1!
    radio.openWritingPipe(pgm_read_64(&pipeOut, vehicleNumber - 1)); // Vehicle Number 1 = Array number 0, so -1!
    radio.write(&data, sizeof(RcData));
  }

  // Receiver (radio tester mode)
  if (operationMode == 1) {
    //radio.openReadingPipe(1, pipeOut[vehicleNumber - 1]);
    radio.openReadingPipe(1, pgm_read_64(&pipeOut, vehicleNumber - 1));
    radio.startListening();
  }
}

//
// =======================================================================================================
// LEGO POWERFUNCTIONS SETUP
// =======================================================================================================
//

void setupPowerfunctions() {
  pfChannel = vehicleNumber - 1;  // channel 0 - 3 is labelled as 1 - 4 on the LEGO devices!

  if (pfChannel > pfMaxAddress) pfChannel = pfMaxAddress;

  pf.begin(3, pfChannel);  // Pin 3, channel 0 - 3
}

//
// =======================================================================================================
// MAIN ARDUINO SETUP (1x during startup)
// =======================================================================================================
//

void setup() {

#ifdef DEBUG
  Serial.begin(115200);
  printf_begin();
  delay(3000);
#endif

  // LED setup
  greenLED.begin(6); // Green LED on pin 5
  redLED.begin(5); // Red LED on pin 6

  // Pinmodes (all other pinmodes are handled inside libraries)
  pinMode(JOYSTICK_BUTTON_LEFT, INPUT_PULLUP);
  pinMode(JOYSTICK_BUTTON_RIGHT, INPUT_PULLUP);
  pinMode(BUTTON_LEFT, INPUT_PULLUP);
  pinMode(BUTTON_RIGHT, INPUT_PULLUP);
  pinMode(BUTTON_SEL, INPUT_PULLUP);
  pinMode(BUTTON_BACK, INPUT_PULLUP);

  // EEPROM setup
  EEPROM.readBlock(addressReverse, joystickReversed); // restore all arrays from the EEPROM
  EEPROM.readBlock(addressNegative, joystickPercentNegative);
  EEPROM.readBlock(addressPositive, joystickPercentPositive);

  if (joystickReversed[0][0] || (!digitalRead(BUTTON_BACK) && !digitalRead(BUTTON_SEL))) { // 255 is EEPROM default after a program download,
    // this indicates that we have to initialise the EEPROM with our default values! Or manually triggered with
    // both "SEL" & "BACK" buttons pressed during switching on!
    memset(joystickReversed, 0, sizeof(joystickReversed)); // init arrays first
    memset(joystickPercentNegative, 100, sizeof(joystickPercentNegative));
    memset(joystickPercentPositive, 100, sizeof(joystickPercentPositive));
    EEPROM.updateBlock(addressReverse, joystickReversed); // then write defaults to EEPROM
    EEPROM.updateBlock(addressNegative, joystickPercentNegative);
    EEPROM.updateBlock(addressPositive, joystickPercentPositive);
  }

  // Switch to radio tester mode, if "Select" button is pressed
  if (digitalRead(BUTTON_BACK) && !digitalRead(BUTTON_SEL)) {
    operationMode = 1;
  }

  // Switch to game mode, if "Back" button is pressed
  if (!digitalRead(BUTTON_BACK) && digitalRead(BUTTON_SEL)) {
    operationMode = 2;
  }

  // Joystick setup
  JoystickOffset(); // Compute all joystick center points
  readJoysticks(); // Then do the first jocstick read

  // Radio setup
  setupRadio();

  // LEGO Powerfunctions setup
  setupPowerfunctions();

  // Display setup
  u8g.setFontRefHeightExtendedText();
  u8g.setDefaultForegroundColor();
  u8g.setFontPosTop();
  u8g.setFont(u8g_font_6x10);

  // Splash screen
  checkBattery();
  activeScreen = 0; // 0 = splash screen active
  drawDisplay();
#ifdef OLED_DEBUG
  activeScreen = 100; // switch to the diagnostics screen
  delay(1500);
  drawDisplay();
#endif
  activeScreen = 1; // switch to the main screen
  delay(1500);
}

//
// =======================================================================================================
// BUTTONS
// =======================================================================================================
//

// Sub function for channel travel adjustment and limitation --------------------------------------
void travelAdjust(boolean upDn) {
  byte inc = 5;
  if (upDn) inc = 5; // Direction +
  else inc = -5; // -

  if ( (menuRow & 0x01) == 0) { // even (2nd column)
    joystickPercentPositive[vehicleNumber][(menuRow - 6) / 2 ] += inc; // row 6 - 12 = 0 - 3
  }
  else { // odd (1st column)
    joystickPercentNegative[vehicleNumber][(menuRow - 5) / 2 ] += inc;  // row 5 - 11 = 0 - 3
  }
  joystickPercentPositive[vehicleNumber][(menuRow - 6) / 2 ] = constrain(joystickPercentPositive[vehicleNumber][(menuRow - 6) / 2 ], 20, 100);
  joystickPercentNegative[vehicleNumber][(menuRow - 5) / 2 ] = constrain(joystickPercentNegative[vehicleNumber][(menuRow - 5) / 2 ], 20, 100);
}

// Main buttons function --------------------------------------------------------------------------
void readButtons() {

  // Every 10 ms
  static unsigned long lastTrigger;
  if (millis() - lastTrigger >= 10) {
    lastTrigger = millis();

    // Left joystick button (Mode 1)
    if (DRE(digitalRead(JOYSTICK_BUTTON_LEFT), leftJoystickButtonState) && (transmissionMode == 1)) {
      data.mode1 = !data.mode1;
      drawDisplay();
    }

    // Right joystick button (Mode 2)
    if (DRE(digitalRead(JOYSTICK_BUTTON_RIGHT), rightJoystickButtonState) && (transmissionMode == 1)) {
      data.mode2 = !data.mode2;
      drawDisplay();
    }

    if (activeScreen <= 10) { // if menu is not displayed ----------

      // Left button: Channel selection +
      if (DRE(digitalRead(BUTTON_LEFT), leftButtonState) && (transmissionMode < 3)) {
        vehicleNumber ++;
        if (vehicleNumber > maxVehicleNumber) vehicleNumber = 1;
        setupRadio(); // Re-initialize the radio with the new pipe address
        setupPowerfunctions(); // Re-initialize the LEGO IR transmitter with the new channel address
        drawDisplay();
      }

      // Right button: Change transmission mode. Radio <> IR
      if (infrared) { // only, if transmitter has IR option
        if (DRE(digitalRead(BUTTON_RIGHT), rightButtonState)) {
          if (transmissionMode < 3) transmissionMode ++;
          else {
            transmissionMode = 1;
            setupRadio(); // Re-initialize radio, if we switch back to radio mode!
          }
          drawDisplay();
        }
      }
      else { // only, if transmitter has no IR option
        // Right button: Channel selection -
        if (DRE(digitalRead(BUTTON_RIGHT), rightButtonState) && (transmissionMode < 3)) {
          vehicleNumber --;
          if (vehicleNumber < 1) vehicleNumber = maxVehicleNumber;
          setupRadio(); // Re-initialize the radio with the new pipe address
          setupPowerfunctions(); // Re-initialize the LEGO IR transmitter with the new channel address
          drawDisplay();
        }
      }
    }
    else { // if menu is displayed -----------
      // Right button: Value -
      if (DRE(digitalRead(BUTTON_RIGHT), rightButtonState)) {
        if (activeScreen == 11) {
          joystickReversed[vehicleNumber][menuRow - 1] = false;
        }
        if (activeScreen == 12) {
          travelAdjust(false); // -
        }
        drawDisplay();
      }

      // Left button: Value +
      if (DRE(digitalRead(BUTTON_LEFT), leftButtonState)) {
        if (activeScreen == 11) {
          joystickReversed[vehicleNumber][menuRow - 1] = true;
        }
        if (activeScreen == 12) {
          travelAdjust(true); // +
        }
        drawDisplay();
      }
    }

    // Menu buttons:

    // Select button: opens the menu and scrolls through menu entries
    if (DRE(digitalRead(BUTTON_SEL), selButtonState) && (transmissionMode == 1)) {
      activeScreen = 11; // 11 = Menu screen 1
      menuRow ++;
      if (menuRow > 4) activeScreen = 12; // 12 = Menu screen 2
      if (menuRow > 12) {
        activeScreen = 11; // Back to menu 1, entry 1
        menuRow = 1;
      }
      drawDisplay();
    }

    // Back / Momentary button:
    if (activeScreen <= 10) { // Momentary button, if menu is NOT displayed
      if (!digitalRead(BUTTON_BACK)) data.momentary1 = true;
      else data.momentary1 = false;
    }
    else { // Goes back to the main screen & saves the changed entries in the EEPROM
      if (DRE(digitalRead(BUTTON_BACK), backButtonState)) {
        activeScreen = 1; // 1 = Main screen
        menuRow = 0;
        drawDisplay();
        EEPROM.updateBlock(addressReverse, joystickReversed); // update changed values in EEPROM
        EEPROM.updateBlock(addressNegative, joystickPercentNegative);
        EEPROM.updateBlock(addressPositive, joystickPercentPositive);
      }
    }
  }
}

//
// =======================================================================================================
// JOYSTICKS
// =======================================================================================================
//

int offset[4]; // the auto calibration offset of each joystick

// Auto-zero subfunction (called during setup, if a pot and no 3 position switch is connected) ----
void JoystickOffset() {
#ifndef CH1Switch
  offset[0] = 512 - analogRead(JOYSTICK_1);
#endif

#ifndef CH2Switch
  offset[1] = 512 - analogRead(JOYSTICK_2);
#endif

#ifndef CH3Switch
  offset[2] = 512 - analogRead(JOYSTICK_3);
#endif

#ifndef CH4Switch
  offset[3] = 512 - analogRead(JOYSTICK_4);
#endif
}

// Mapping and reversing subfunction ----
byte mapJoystick(byte input, byte arrayNo) {
  int reading[4];
  reading[arrayNo] = analogRead(input) + offset[arrayNo]; // read joysticks and add the offset
  reading[arrayNo] = constrain(reading[arrayNo], (1023 - range[arrayNo]), range[arrayNo]); // then limit the result before we do more calculations below

#ifndef CONFIG_4_CH // In most "car style" transmitters, less than one half of the throttle potentiometer range is used for the reverse. So we have to enhance this range!
  if (reading[2] < (range[2] / 2) ) {
    reading[2] = constrain(reading[2], reverseEndpoint, (range[2] / 2)); // limit reverse range, which will be mapped later on
    reading[2] = map(reading[2], reverseEndpoint, (range[2] / 2), 0, (range[2] / 2)); // reverse range mapping (adjust reverse endpoint in transmitterConfig.h)
  }
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
void loop() {

  // only read analog inputs in transmitter (0) or game mode (2)
  if (operationMode == 0 || operationMode == 2) {

    // Read joysticks
    readJoysticks();

    // Read Potentiometer
    readPotentiometer();
  }

  // Transmit data via infrared or 2.4GHz radio
  if (operationMode == 1) readRadio(); // 2.4 GHz radio tester
  if (operationMode == 0) {
    transmitRadio(); // 2.4 GHz radio
    if (transmissionMode == 2) transmitLegoIr(); // LEGO Infrared
    if (transmissionMode == 3) transmitMeccanoIr(); // MECCANO Infrared
  }

  // Refresh display every 200 ms in tester mode (otherwise only, if value has changed)
  static unsigned long lastDisplay;
  if (operationMode == 1 && millis() - lastDisplay >= 200) {
    lastDisplay = millis();
    drawDisplay();
  }

  // Atari Pong game :-)
  if (operationMode == 2) pong();

  // If not in game mode:
  else {
    led(); // LED control
    checkBattery(); // Check battery
    readButtons();
  }
}

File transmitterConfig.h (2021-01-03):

#ifndef transmitterConfig_h
#define transmitterConfig_h

#include "Arduino.h"

#define CONFIG_WLTOYS_2 // <- Select the correct transmitter configuration here before uploading!

//
// =======================================================================================================
// TRANSMITTEER SPECIFIC CONFIGURATIONS
// =======================================================================================================
//

// Configuration for the standard "Micro RC" transmitter with 4 channels and IR support----------------------
#ifdef CONFIG_MICRO_RC
// Battery type
const float cutoffVoltage = 4.4; // 4 x Eneloop cell
const float diodeDrop = 0.72;

// Channels, we have
#define CH1
#define CH2 
#define CH3
#define CH4

// Infrared
boolean infrared = true;

// Board type
const float boardVersion = 1.1; // Board revision (MUST MATCH WITH YOUR BOARD REVISION!!)

// Joystick calibration
int range[4] = {1023, 1023, 1023, 1023}; // 1023, if entire pot wiper range is used (CH1, 2, 3, 4)
int reverseEndpoint = 0; // the point, where the throttle joystick hits its reverse end stop

#endif

// Configuration for a 2 channel transmitter with steering wheel. No IR support----------------------
#ifdef CONFIG_2_CH
// Battery type
const float cutoffVoltage = 4.4; // 4 x Eneloop cell
const float diodeDrop = 0.3;

// Channels, we have
#define CH1
#define CH3

// Infrared
boolean infrared = false;

// Board type
const float boardVersion = 1.1; // Board revision (MUST MATCH WITH YOUR BOARD REVISION!!)

// Joystick calibration
int range[4] = {820, 820, 820, 820}; // 1023, if entire pot wiper range is used (CH1, 2, 3, 4)
int reverseEndpoint = 273; // the point, where the throttle joystick hits its reverse end stop

#endif

// Configuration for a 2+1 channel transmitter with steering wheel. No IR support----------------------
#ifdef CONFIG_3_CH
// Battery type
const float cutoffVoltage = 4.4; // 4 x Eneloop cell
const float diodeDrop = 0.3;

// Channels, we have
#define CH1
#define CH2 // switch with one resistor to gnd and one to vcc (for 3 speed gearbox) 
#define CH3

// 3 position switches, we have (= no auto calibtation for these channels during startup)
#define CH2Switch

// Infrared
boolean infrared = false;

// Board type
const float boardVersion = 1.1; // Board revision (MUST MATCH WITH YOUR BOARD REVISION!!)

// Joystick calibration
int range[4] = {820, 820, 820, 820}; // 1023, if entire pot wiper range is used (CH1, 2, 3, 4)
int reverseEndpoint = 273; // the point, where the throttle joystick hits its reverse end stop

#endif

// Configuration for a 2+1 channel transmitter with steering wheel. Based on a WLtoys transmitter. No IR support----------------------
#ifdef CONFIG_WLTOYS
// Battery type
const float cutoffVoltage = 4.4; // 4 x Eneloop cell
const float diodeDrop = 0.0; // No protection diode in this transmitter

// General settings
#define ledInversed // LED common is wired to VCC, so we have to inverse the logic!

// Channels, we have
#define CH1 // Steering
#define CH2 // switch with one resistor to gnd and one to vcc (for 3 speed gearbox) 
#define CH3 // Throttle

// 3 position switches, we have (= no auto calibtation for these channels during startup)
#define CH2Switch

// Infrared
boolean infrared = false;

// Board type
const float boardVersion = 1.1; // Board revision (MUST MATCH WITH YOUR BOARD REVISION!!)

// Joystick calibration
int range[4] = {900, 900, 900, 900}; // 1023, if entire pot wiper range is used (CH1, 2, 3, 4)
int reverseEndpoint = 170; // the point, where the throttle joystick hits its reverse end stop

#endif

// Configuration for a 2+2 channel transmitter with steering wheel. Based on a WLtoys transmitter. No IR support----------------------
#ifdef CONFIG_WLTOYS_2
// Battery type
const float cutoffVoltage = 4.4; // 4 x Eneloop cell
const float diodeDrop = 0.0; // No protection diode in this transmitter

// General settings
#define ledInversed // LED common is wired to VCC, so we have to inverse the logic!

// Channels, we have
#define CH1 // Steering
#define CH2 // switch with one resistor to gnd and one to vcc (for 3 speed gearbox) 
#define CH3 // Throttle
#define CH4 // 3 x push buttons: 1 pressed = 0V, 2 pressed = 0.76V, 3 pressed = 3.3V, no button pressed = 1.65V

// 3 position switches, we have (= no auto calibtation for these channels during startup)
#define CH2Switch
#define CH4Switch

// Infrared
boolean infrared = false;

// Board type
const float boardVersion = 1.1; // Board revision (MUST MATCH WITH YOUR BOARD REVISION!!)

// Joystick calibration
int range[4] = {890, 900, 900, 900}; // 1023, if entire pot wiper range is used (CH1, 2, 3, 4)
int reverseEndpoint = 170; // the point, where the throttle joystick hits its reverse end stop

#endif
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

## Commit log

2016-08-07 Schematic added
2016-08-20 Pinout changed for final PCB
2016-08-20 Initial PCB
    [Micro RC Transmitter.brd, Micro RC Transmitter.sch]
2016-09-03 V1.1: Channel direction reversing menu added
    Independent for each vehicle. Configuration is stored in EEPROM
    [RC_Transmitter.ino]
2016-09-05 New board revision 1.2
    separate voltage regulator for NRF24L01 radio transmitter. Allows to use a a model with power amplifier.
    [Micro RC Transmitter.brd, Micro RC Transmitter.sch]
2016-09-10 V1.2: Configuration menu enhanced with servo travel adjustment
2016-09-15 LED resistor values increased
    [Micro RC Transmitter.brd, Micro RC Transmitter.sch]
2016-09-15 Version 1.21 with different transmission power levels, depending on board version
2016-10-02 IR code for "MECCANO" motors added. Multichannel transmission.
2016-10-08 V1.41: Battery voltage now indicated correctly on 5V systems
    [RC_Transmitter.ino]
2016-11-05 V1.42: Vehicle battery state change OLED bug fixed
    [RC_Transmitter.ino]
2016-11-19 V 1.6: automatic joystick calibration
2017-04-27 V1.7: support for 2CH car style transmitters with steering wheel
2017-12-05 PCB picture added
2017-12-10 V2.01: bug in mapJoystick() solved
    [RC_Transmitter.ino]
2018-05-14 STL data for 3D printing
    [Transmitter Cover.stl, Transmitter Frame.stl]
2019-04-09 V2.1: new 3CH configuration
    for additional 3 position switch on pin A0
2019-04-09 V2.1: new 3CH configuration
    for 3 position switch on pin A0
2020-04-18 v2.3: support for buttons on CH4 added

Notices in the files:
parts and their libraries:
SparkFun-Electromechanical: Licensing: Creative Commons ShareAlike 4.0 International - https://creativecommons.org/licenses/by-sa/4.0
